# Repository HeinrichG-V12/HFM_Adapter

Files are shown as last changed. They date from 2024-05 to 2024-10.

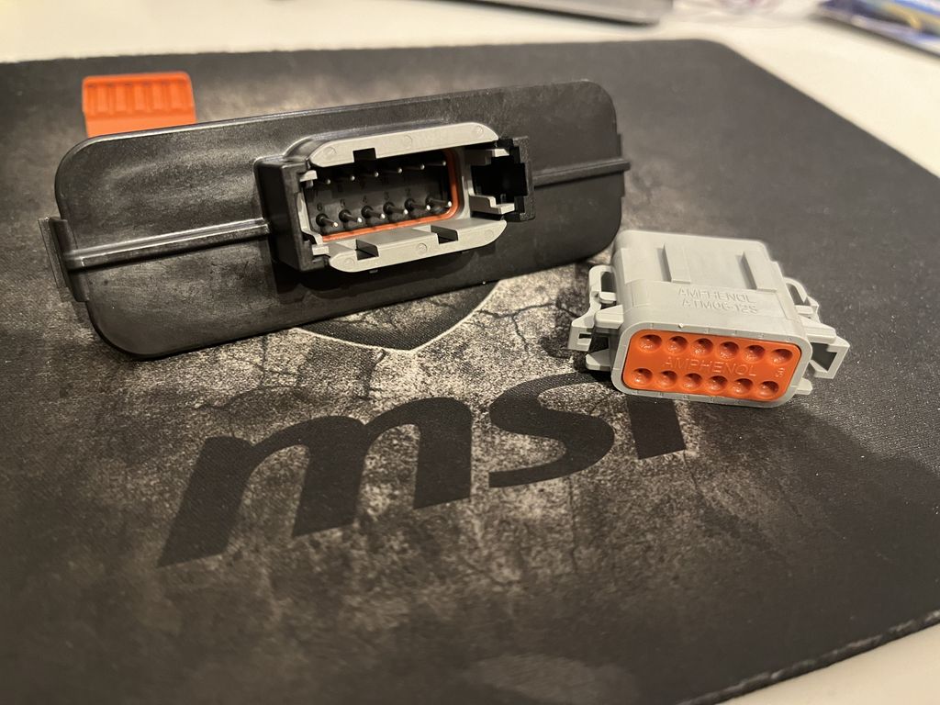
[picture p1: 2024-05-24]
hardware/Housing/003.jpg

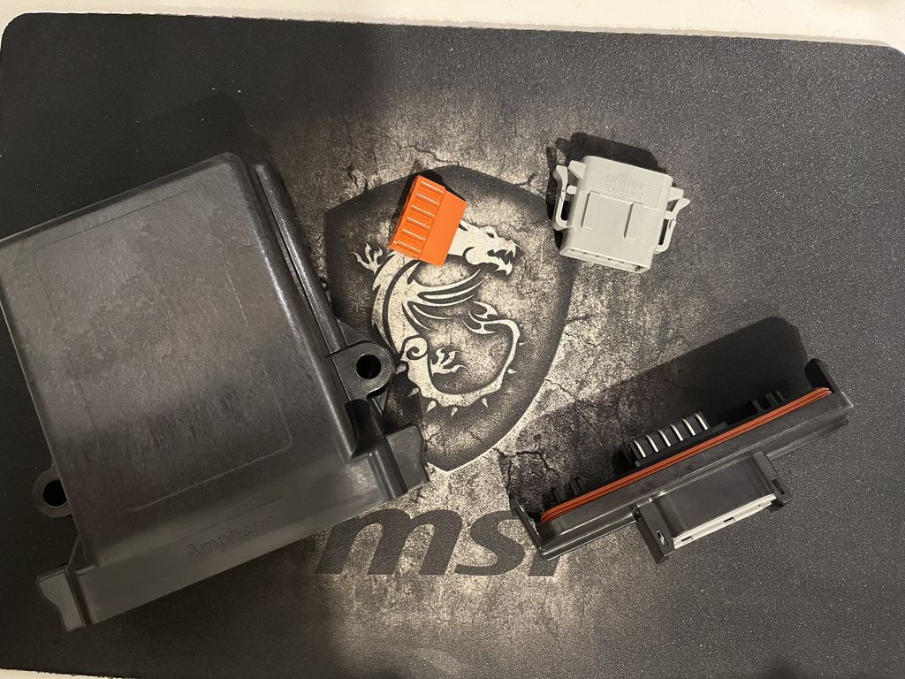
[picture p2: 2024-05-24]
hardware/Housing/001.jpg

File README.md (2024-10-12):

# HFM Adapter

## With this adapter it is possible to replace any HLM with any HFM

## Development status

- Hardware: Revision 1.0 done
  - [**Revision 1.0 is erroneous, swapped pins on TLE42764 and TLE4252D.**](./hardware/Rev1.0/README.md)
  - [Revision 1.1 done](./hardware/Rev1.1/README.md)
- Software: Version 1.0 done

### HFM Adapter based on

- STM32 G431KB Nucleo-32 Board
- ST M24M02 2MBit serial I²C EEPROM to store the tables and configuration
- TI REF02 +5.0v precision voltage reference, +-0.2%
- Infineon TLE4252D tracking regulator 250mA
- TI OPA2992 output operation amplifier

### Nucleo-32 modifications

A few changes need to be made to the Nucleo-32 board before it can be used:

- SB1 and SB12 removed (disconnect PA2 and PA3 from T_VCP_TX and T_VCP_RX of ST-Link)
- SB14 installed (connect PA3 to CN3 Pin 10)
- SB9 and SB10 installed (connect external 24MHz HSE CLK)

### Features

- Automotive grade components
- 4 layer PCB
- Configuration via TunerStudio

### Inputs

- two HFM buffered analog inputs (0v - 5v) with overvoltage protection 
- USB for configuration
- VBat input for voltage monitoring 

### Outputs

- two analog outputs
- two precision reference 5.0v outputs for HFM
- two Vbat outputs for HFM

### Housing

- Header: Amphenol ATM13-12PA
- Enclosure: Amphenol AIPXE-325X4

### Pin terminal for BMW M70 adapter

- pin terminal 1252 1718125
- connector boot 1252 1711262
- pins
  - 0.5 - 1.0mm² 6113 1376191
  - 1.0mm² - 2.5mm² 6113 1376193
  - 2.5mm² - 4.0mm² 6113 1376195

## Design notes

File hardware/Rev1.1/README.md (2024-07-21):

# HFM Adapter

## Revision 1.1

[Schematic](./hfm_adapter_nucleo-32.pdf)

Pinout

|Pin#|Wire size|Main color|Second color|Signal|
|----|---|---|---|---|
|1|0.5mm²|brown|-|signal ground|
|2|0.5mm²|brown|-|signal ground|
|3|0.5mm²|red|blue|VBat|
|4|0.5mm²|red|blue|VBat|
|5|0.5mm²|violett|black|5v reference voltage for HFM|
|6|0.5mm²|brown|-|signal ground|
|7|0.5mm²|red|blue|VBat|
|8|0.5mm²|violet|black|5v reference voltage for HFM|
|9|0.5mm²|violet|yellow|Channel 1 input from HFM|
|10|0.5mm²|orange|yellow|Channel 2 input from HFM|
|11|0.5mm²|violet|green|Channel 1 output to ECM|
|12|0.5mm²|orange|green|Channel 2 output to ECM|

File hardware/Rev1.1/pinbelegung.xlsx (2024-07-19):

Pin# | Querrschnitt | Hauptfarbe | Zusatzfarbe | Signal
1 | 0,5mm² | braun | - | Signalmasse
2 | 0,5mm² | braun | - | Signalmasse
3 | 0,5mm² | rot | blau | Ubat
4 | 0,5mm² | rot | blau | Ubat
5 | 0,5mm² | violett | schwarz | 5v Referenzspannung für HFM, falls notwendig
6 | 0,5mm² | braun | - | Signalmasse
7 | 0,5mm² | rot | blau | Ubat
8 | 0,5mm² | orange | schwarz | 5v Referenzspannung für HFM, falls notwendig
9 | 0,5mm² | violett | gelb | Kanal 1 Eingang vom HFM
10 | 0,5mm² | orange | gelb | Kanal 2 Eingang vom HFM
11 | 0,5mm² | violett | grün | Kanal 1 Ausgang zum Auto
12 | 0,5mm² | orange | grün | Kanal 2 Ausgang zum Auto

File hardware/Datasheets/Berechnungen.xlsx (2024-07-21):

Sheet: Tabelle1
Signature | 27
Version | 3
Versioninfo | 34
 | 64
hfmIn_voltage | 64 | 1
hfmIn_voltage | 65 | 2
hfmIn_voltage | 66 | 3
hfmIn_voltage | 67 | 4
hfmIn_voltage | 68 | 5
hfmIn_voltage | 69 | 6
hfmIn_voltage | 70 | 7
hfmIn_voltage | 71 | 8
hfmIn_voltage | 72 | 9
hfmIn_voltage | 73 | 10
hfmIn_voltage | 74 | 11
hfmIn_voltage | 75 | 12
hfmIn_voltage | 76 | 13
hfmIn_voltage | 77 | 14
hfmIn_voltage | 78 | 15
hfmIn_voltage | 79 | 16
hfmIn_voltage | 80 | 17
hfmIn_voltage | 81 | 18
hfmIn_voltage | 82 | 19
hfmIn_voltage | 83 | 20
hfmIN_airmass | 84 | 1
hfmIN_airmass | 85 | 2
hfmIN_airmass | 86 | 3
hfmIN_airmass | 87 | 4
hfmIN_airmass | 88 | 5
hfmIN_airmass | 89 | 6
hfmIN_airmass | 90 | 7
hfmIN_airmass | 91 | 8
hfmIN_airmass | 92 | 9
hfmIN_airmass | 93 | 10
hfmIN_airmass | 94 | 11
hfmIN_airmass | 95 | 12
hfmIN_airmass | 96 | 13
hfmIN_airmass | 97 | 14
hfmIN_airmass | 98 | 15
hfmIN_airmass | 99 | 16
hfmIN_airmass | 100 | 17
hfmIN_airmass | 101 | 18
hfmIN_airmass | 102 | 19
hfmIN_airmass | 103 | 20
hfmOUT_voltage | 104 | 1
hfmOUT_voltage | 105 | 2
hfmOUT_voltage | 106 | 3
hfmOUT_voltage | 107 | 4
hfmOUT_voltage | 108 | 5
hfmOUT_voltage | 109 | 6
hfmOUT_voltage | 110 | 7
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

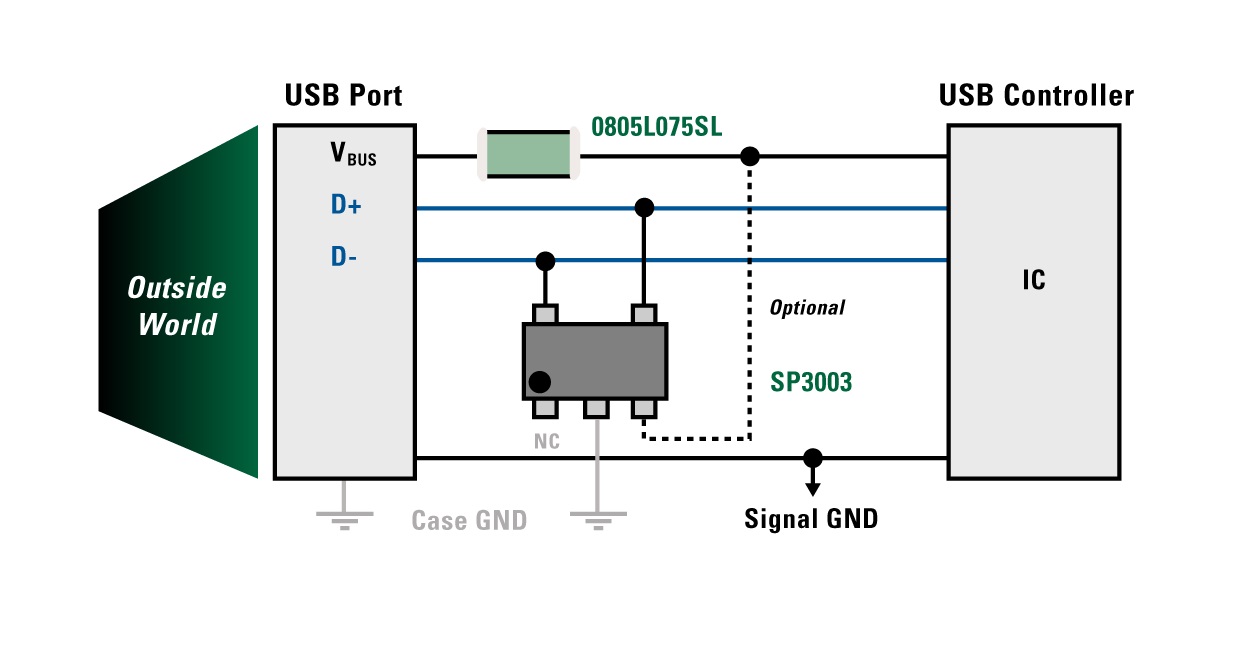
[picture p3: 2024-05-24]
hardware/Datasheets/02apr14protectfig3.jpg

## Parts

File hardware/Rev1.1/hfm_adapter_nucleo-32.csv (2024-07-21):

Qty | Value | Device | Package | Parts | Description | ARROW_PART_NUMBER | ARROW_PRICE-STOCK | DESCRIPTION | HEIGHT | MANUFACTURER_NAME | MANUFACTURER_PART_NUMBER | MF | MOUSER_PART_NUMBER | MOUSER_PRICE-STOCK | MPN | OC_FARNELL | OC_NEWARK | RS_PART_NUMBER | RS_PRICE-STOCK | SPICEPREFIX
10 | 100nF | C-EUC0805 | C0805 | C2, C4, C5, C8, C9, C10, C13, C14, C15, C17 | CAPACITOR, European symbol |  |  |  |  |  |  |  |  |  |  |  |  |  |  | C
1 | 100nF | C-EUC1206 | C1206 | C6 | CAPACITOR, European symbol |  |  |  |  |  |  |  |  |  |  |  |  |  |  | C
8 | 10k 0.5% | R-EU_R0805 | R0805 | R4, R6, R8, R11, R12, R14, R15, R16 | RESISTOR, European symbol |  |  |  |  |  |  |  |  |  |  |  |  |  |  | R
1 | 10µF 50v | CPOL-EUD | PANASONIC_D | C12 | POLARIZED CAPACITOR, European symbol |  |  |  |  |  |  |  |  |  |  |  |  |  |  | C
3 | 1uF | C-EUC0805 | C0805 | C1, C11, C16 | CAPACITOR, European symbol |  |  |  |  |  |  |  |  |  |  |  |  |  |  | C
1 | 22µF | CPOL-EUC | PANASONIC_C | C7 | POLARIZED CAPACITOR, European symbol |  |  |  |  |  |  |  |  |  |  |  |  |  |  | C
1 | 30k 0.5% | R-EU_R0805 | R0805 | R9 | RESISTOR, European symbol |  |  |  |  |  |  |  |  |  |  |  |  |  |  | R
2 | 470k | R-EU_R0805 | R0805 | R18, R19 | RESISTOR, European symbol |  |  |  |  |  |  |  |  |  |  |  |  |  |  | R
2 | 4k7 | R-EU_R0805 | R0805 | R1, R2 | RESISTOR, European symbol |  |  |  |  |  |  |  |  |  |  |  |  |  |  | R
4 | 5k6 0.5% | R-EU_R0805 | R0805 | R3, R5, R7, R10 | RESISTOR, European symbol |  |  |  |  |  |  |  |  |  |  |  |  |  |  | R
1 | 82k 0.5% | R-EU_R0805 | R0805 | R13 | RESISTOR, European symbol |  |  |  |  |  |  |  |  |  |  |  |  |  |  | R
1 | ADR01_02_03 | ADR01_02_03 | SOIC8 | IC9
1 | ATM13-12PX | ATM13-12PX | ATM13-12PX | HOUSING
1 | B5819W | SHOTTKYSOD-123 | SOD-123 | D4
1 | BAT54S | BAT54S | SOT23 | D1 | Schottky barrier (double) diodesPlanar Schottky barrier diodes encapsulated in a SOT23
1 | IP4234CZ6,115 | IP4234CZ6,115 | SOT95P275X110-6N | IC3 | ESD Suppressors / TVS Diodes ESD PRTCT/HI SPD INF ZEN LOW VLTG CLMP | IP4234CZ6,115 | null?region=nac | ESD Suppressors / TVS Diodes ESD PRTCT/HI SPD INF ZEN LOW VLTG CLMP | 1.1mm | Nexperia | IP4234CZ6,115 |  | 771-IP4234CZ6 | https://www.mouser.co.uk/ProductDetail/Nexperia/IP4234CZ6115?qs=iS%252BvaFGfLooAQ%252BprbRTkIg%3D%3D
1 | KUSBVX-BS1N | KUSBVX-BS1N | KUSBVX-BS1N | X2 | USB B-type Receptacle Vertical, 4 Position, Through Hole
1 | LPS25HBTR | LPS25HBTR | LPS25HBTR | IC4 | Board Mount Pressure Sensor 26kPa to 126kPa Absolute 10-Pin HLGA T/R | LPS25HBTR | https://www.arrow.com/en/products/lps25hbtr/stmicroelectronics | Board Mount Pressure Sensor 26kPa to 126kPa Absolute 10-Pin HLGA T/R | 0.8mm | STMicroelectronics | LPS25HBTR |  | 511-LPS25HBTR | https://www.mouser.co.uk/ProductDetail/STMicroelectronics/LPS25HBTR?qs=GDOUxV2YAh9IvjPyBKWGzQ%3D%3D
1 | M24M02 | EEPROM_I2CSO8 | SO8 | IC2 | I²C EEPROM IC, i.e. FT24C256A
1 | NUCLEO-G431KB | NUCLEO-G431KB | DIPS1524W66P254L5029H1500Q30N | IC1 | STM32 Nucleo-32 development board | NUCLEO-F303K8 | https://www.arrow.com/en/products/nucleo-f303k8/stmicroelectronics | STM32 Nucleo-32 development board | 15mm | STMicroelectronics | NUCLEO-F303K8 |  |  |  |  |  |  | 9092862 | http://uk.rs-online.com/web/p/products/9092862
1 | OPA2172D | OPA2172D | SO08 | IC11 | Operational Amplifier |  |  |  |  |  |  | TEXAS INSTRUMENTS |  |  | OPA2234U | 1212441 | 96K4523
1 | OPA2992D | OPA2172D | SO08 | IC10 | Operational Amplifier |  |  |  |  |  |  | TEXAS INSTRUMENTS |  |  | OPA2234U | 1212441 | 96K4523
1 | S1J | SHOTTKYSMA | DO214AC | D5
1 | SMBJ36CA | TVS_BIA | DO214AA | D2
1 | SRV05-4MR6T1GTSSOP6 | SRV05-4MR6T1GTSSOP6 | TSSOP6 | IC6 |  | SRV05-4MR6T1G | https://www.arrow.com/en/products/srv05-4mr6t1g/on-semiconductor?region=nac | ON SEMICONDUCTOR - SRV05-4MR6T1G - ESD Protection Device, 17.5 V, TSOP, 6 Pins, 300 W | 1.1mm | onsemi | SRV05-4MR6T1G |  | 863-SRV05-4MR6T1G | https://www.mouser.co.uk/ProductDetail/onsemi/SRV05-4MR6T1G?qs=unWjWFgkqcg61n2fM3DdZg%3D%3D
1 | TLE4252D | TLE4252D | TO-252-5-INF | IC7 | Infineon Tracking regualtor
1 | TLE42764DV | TLE42764DV | TO-252-5-INF | IC8

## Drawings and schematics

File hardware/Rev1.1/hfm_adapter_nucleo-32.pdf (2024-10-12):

A

A

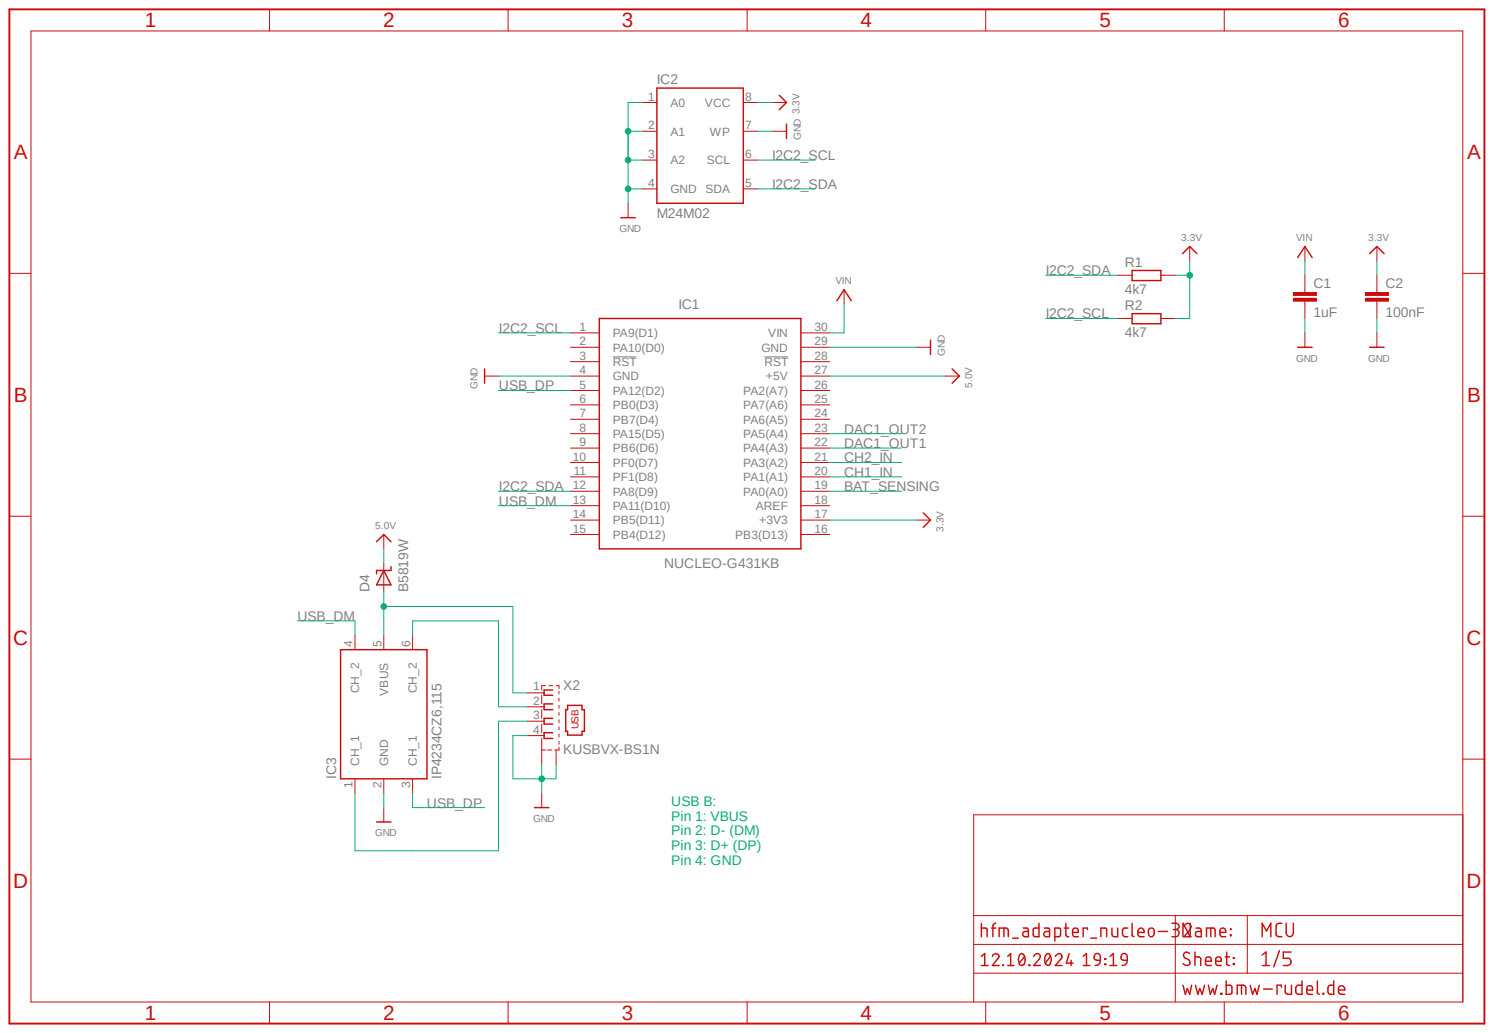
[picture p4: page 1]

A

A

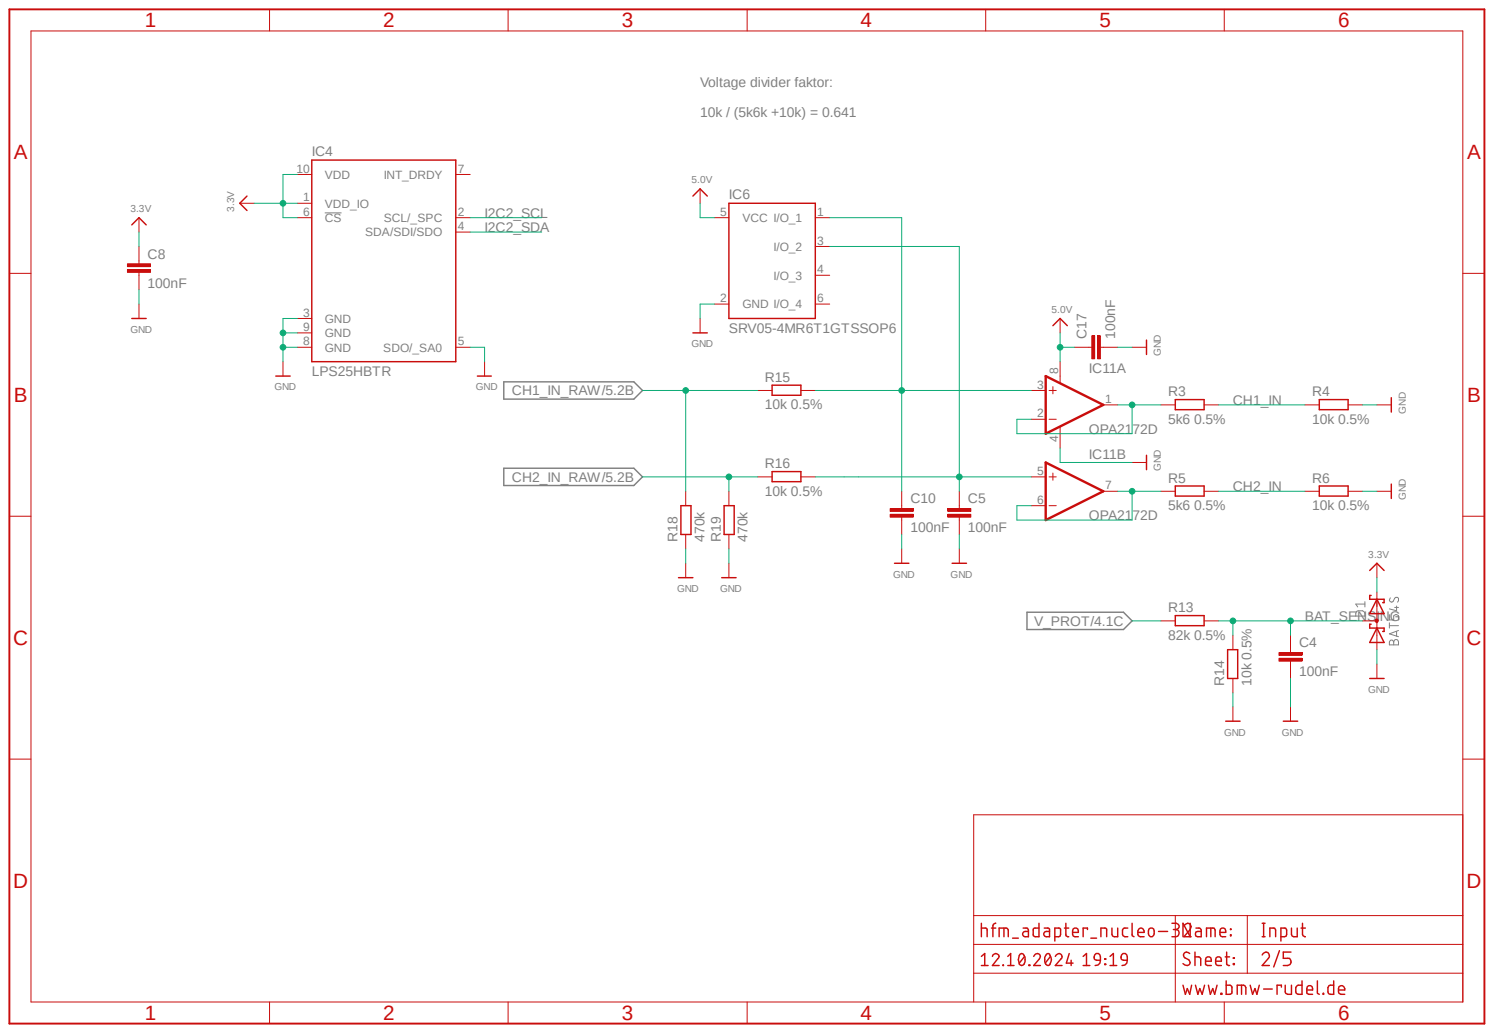
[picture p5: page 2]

A

A

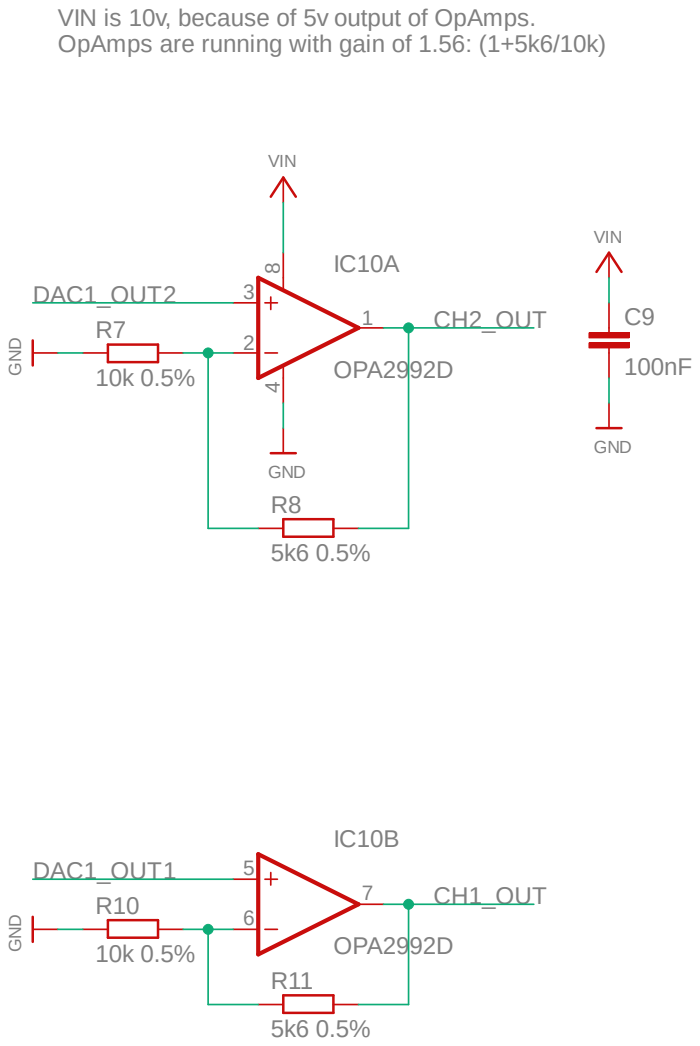
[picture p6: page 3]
GND; GNDGND GND100nF; VIN; OPA2992D; CH2_OUT; CH1_OUT; DAC1_OUT1; DAC1_OUT2

VIN is 10v, because of 5v output of OpAmps.
OpAmps are running with gain of 1.56: (1+5k6/10k)

A

A

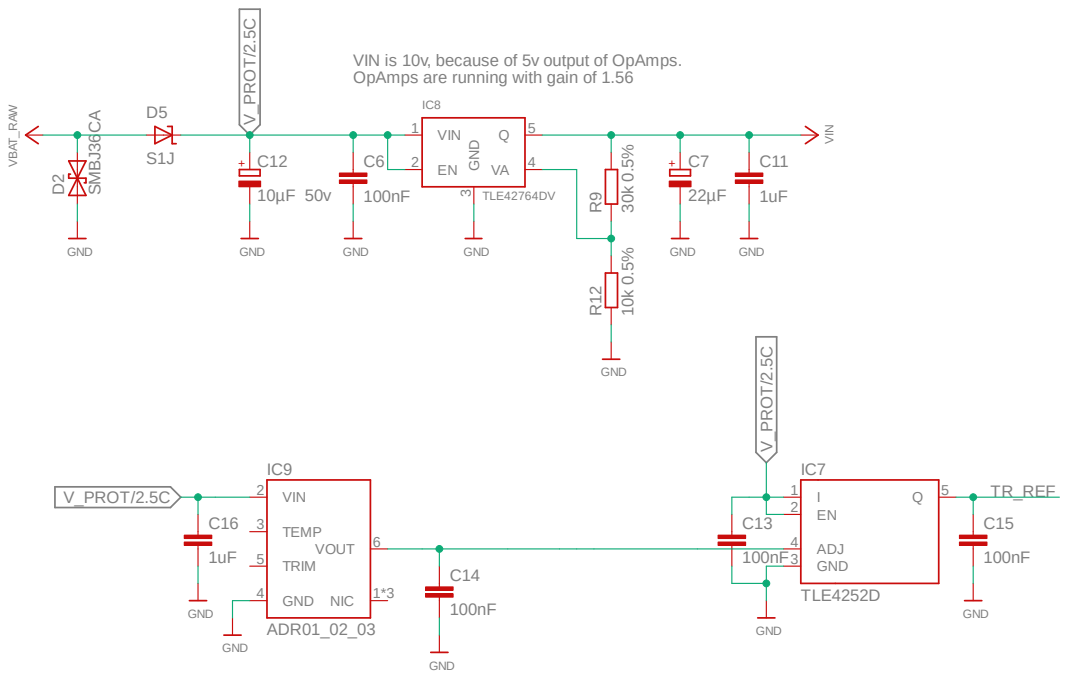
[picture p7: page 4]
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

A

A

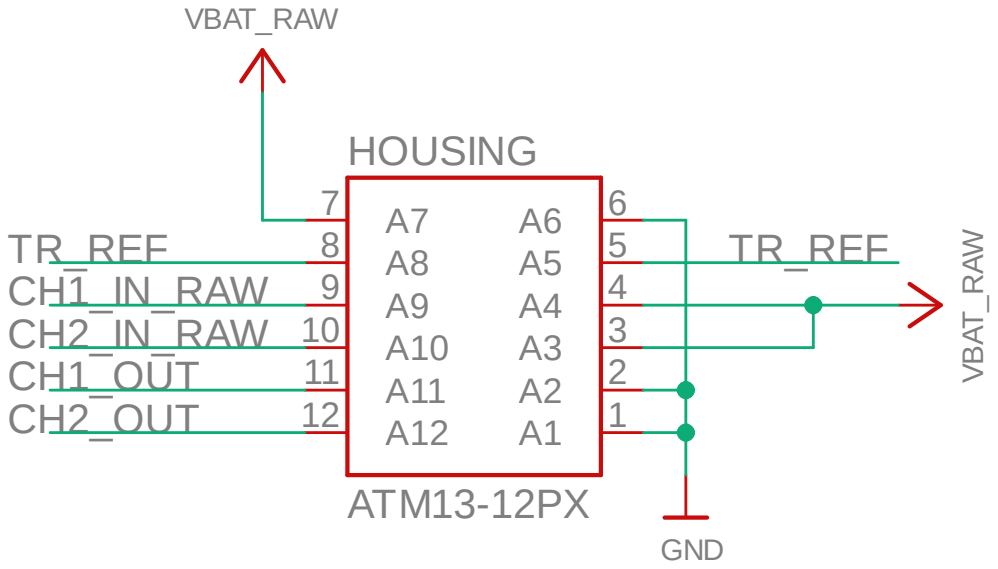
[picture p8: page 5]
ATM13-12PX; GND; VBAT_RAW; VBAT_RAWA6 6 A5 5 A4 4 A3 3 A2 2; HOUSING; CH1_IN_RAW CH2_IN_RAW; TR_REFTR_REF; CH1_OUT CH2_OUT

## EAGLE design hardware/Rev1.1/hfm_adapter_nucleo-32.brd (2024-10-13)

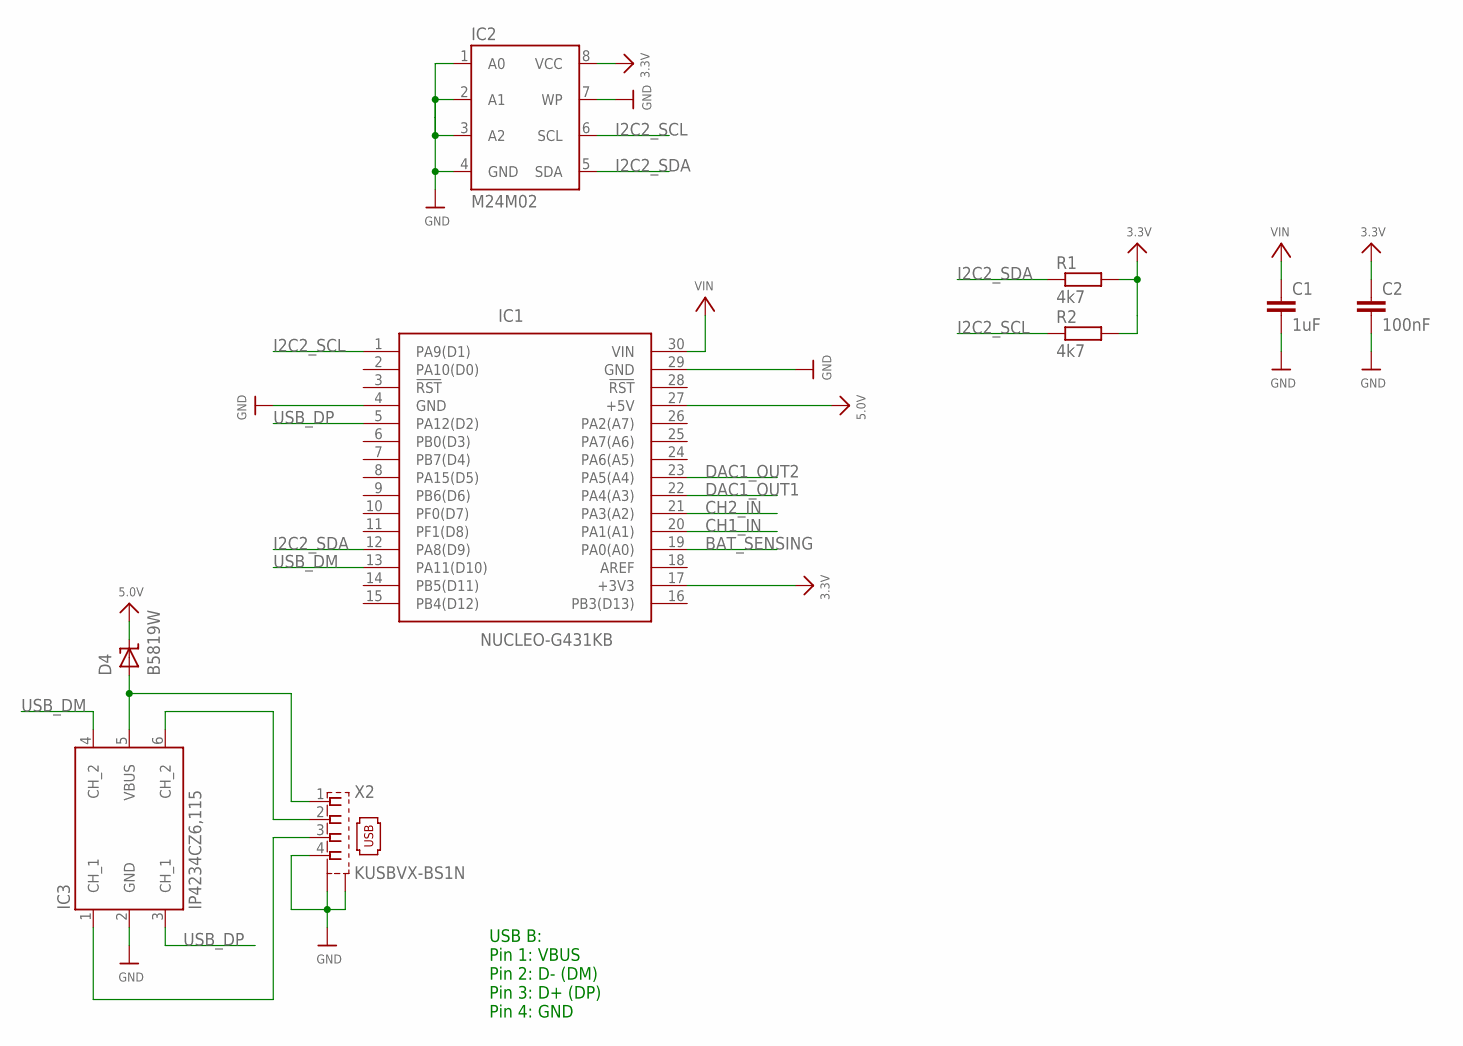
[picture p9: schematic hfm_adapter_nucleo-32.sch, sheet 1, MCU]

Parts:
C1: 1uF; C0805
C2: 100nF; C0805
D4: B5819W; SOD-123
IC1: NUCLEO-G431KB; DIPS1524W66P254L5029H1500Q30N
IC2: M24M02; SO8
IC3: IP4234CZ6,115; SOT95P275X110-6N
R1, R2: 4k7; R0805
X2: KUSBVX-BS1N

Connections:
3.3V: C2.1, IC1.17 (+3V3), IC2.8 (VCC), R1.2, R2.2; also elsewhere on the board
5.0V: D4.C, IC1.27 (+5V); also elsewhere on the board
BAT_SENSING: IC1.19 (PA0(A0)); also elsewhere on the board
CH1_IN: IC1.20 (PA1(A1)); also elsewhere on the board
CH2_IN: IC1.21 (PA3(A2)); also elsewhere on the board
DAC1_OUT1: IC1.22 (PA4(A3)); also elsewhere on the board
DAC1_OUT2: IC1.23 (PA5(A4)); also elsewhere on the board
GND: C1.2, C2.2, IC1.4 (GND), IC1.29 (GND), IC2.1 (A0), IC2.2 (A1), IC2.3 (A2), IC2.4 (GND), IC2.7 (WP), IC3.2 (GND), X2.4, X2.M1 (S1), X2.M2 (S2); also elsewhere on the board
I2C2_SCL: IC1.1 (PA9(D1)), IC2.6 (SCL), R2.1; also elsewhere on the board
I2C2_SDA: IC1.12 (PA8(D9)), IC2.5 (SDA), R1.1; also elsewhere on the board
unnamed: IC3.1 (CH_1), X2.3
unnamed: IC3.6 (CH_2), X2.2
unnamed: D4.A, IC3.5 (VBUS), X2.1
USB_DM: IC1.13 (PA11(D10)), IC3.4 (CH_2)
USB_DP: IC1.5 (PA12(D2)), IC3.3 (CH_1)
VIN: C1.1, IC1.30 (VIN); also elsewhere on the board

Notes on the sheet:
USB B: Pin 1: VBUS Pin 2: D- (DM) Pin 3: D+ (DP) Pin 4: GND

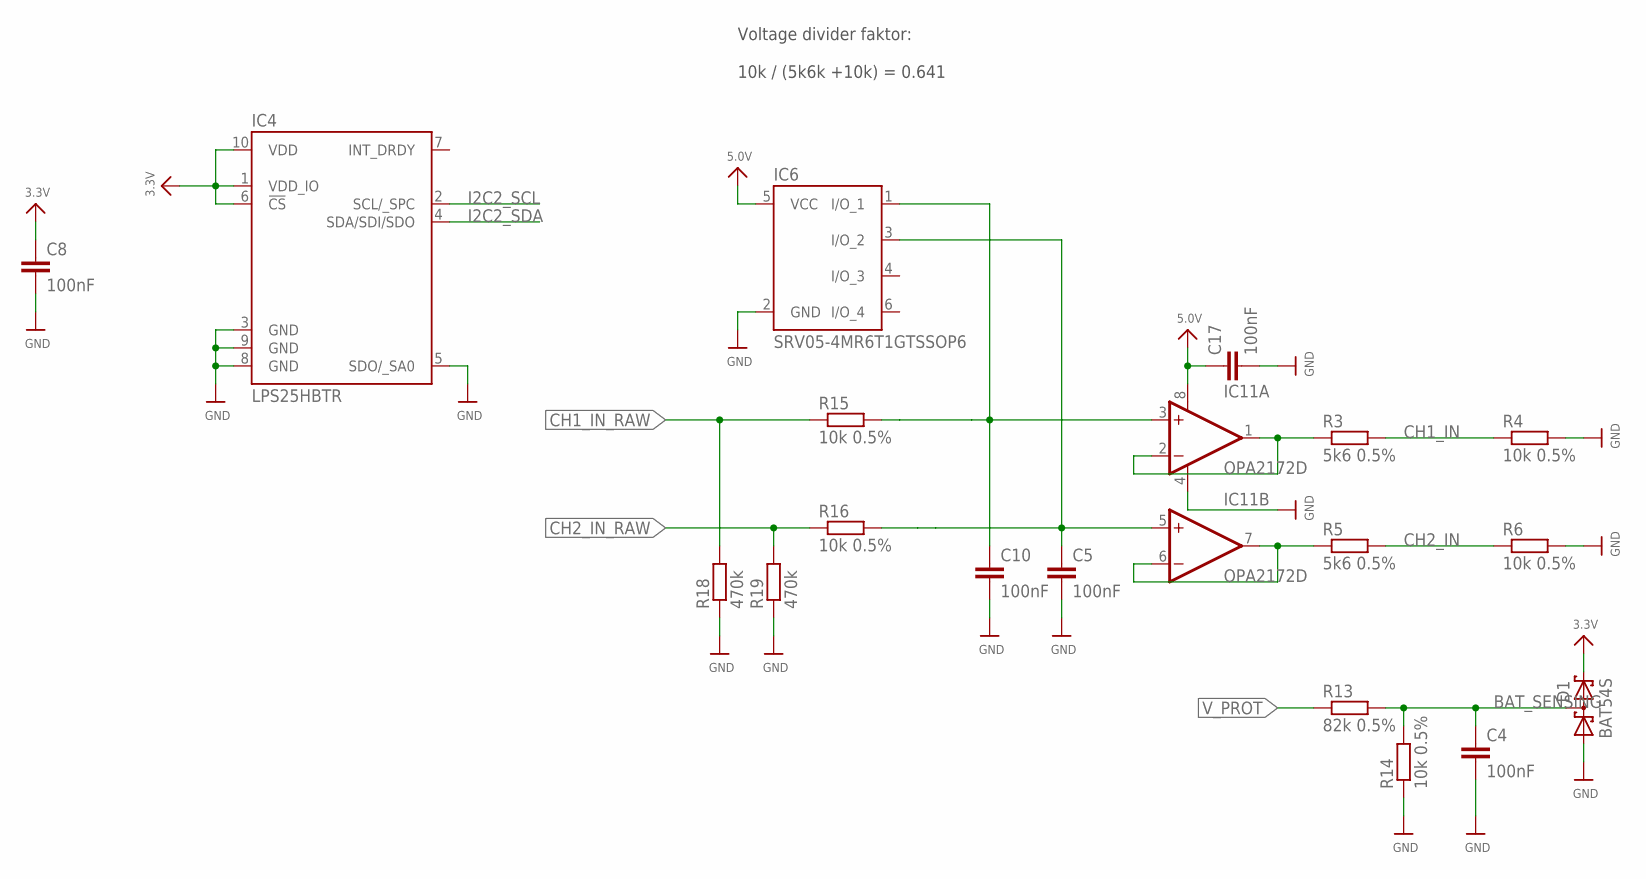
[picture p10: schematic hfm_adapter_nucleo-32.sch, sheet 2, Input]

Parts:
C4, C5, C8, C10, C17: 100nF; C0805
D1: BAT54S; SOT23
IC4: LPS25HBTR
IC6: SRV05-4MR6T1GTSSOP6; TSSOP6
IC11: OPA2172D; SO08
R3, R5: 5k6 0.5%; R0805
R4, R6, R14, R15, R16: 10k 0.5%; R0805
R13: 82k 0.5%; R0805
R18, R19: 470k; R0805

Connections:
3.3V: C8.1, D1.2 (K2), IC4.1 (VDD_IO), IC4.6 (!CS), IC4.10 (VDD); also elsewhere on the board
5.0V: C17.1, IC6.5 (VCC), IC11.8 (V+); also elsewhere on the board
BAT_SENSING: C4.1, D1.3 (K1A2), R13.2, R14.2; also elsewhere on the board
CH1_IN: R3.2, R4.1; also elsewhere on the board
CH1_IN_RAW: R15.1, R18.2; also elsewhere on the board
CH2_IN: R5.2, R6.1; also elsewhere on the board
CH2_IN_RAW: R16.1, R19.2; also elsewhere on the board
GND: C4.2, C5.2, C8.2, C10.2, C17.2, D1.1 (A1), IC4.3 (GND), IC4.5 (SDO/_SA0), IC4.8 (GND), IC4.9 (GND), IC6.2 (GND), IC11.4 (V-), R4.2, R6.2, R14.1, R18.1, R19.1; also elsewhere on the board
I2C2_SCL: IC4.2 (SCL/_SPC); also elsewhere on the board
I2C2_SDA: IC4.4 (SDA/SDI/SDO); also elsewhere on the board
unnamed: IC11.1 (OUT), IC11.2 (-IN), R3.1
unnamed: C10.1, IC6.1 (I/O_1), IC11.3 (+IN), R15.2
unnamed: IC11.6 (-IN), IC11.7 (OUT), R5.1
unnamed: C5.1, IC6.3 (I/O_2), IC11.5 (+IN), R16.2
V_PROT: R13.1; also elsewhere on the board

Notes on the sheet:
Voltage divider faktor: 10k / (5k6k +10k) = 0.641

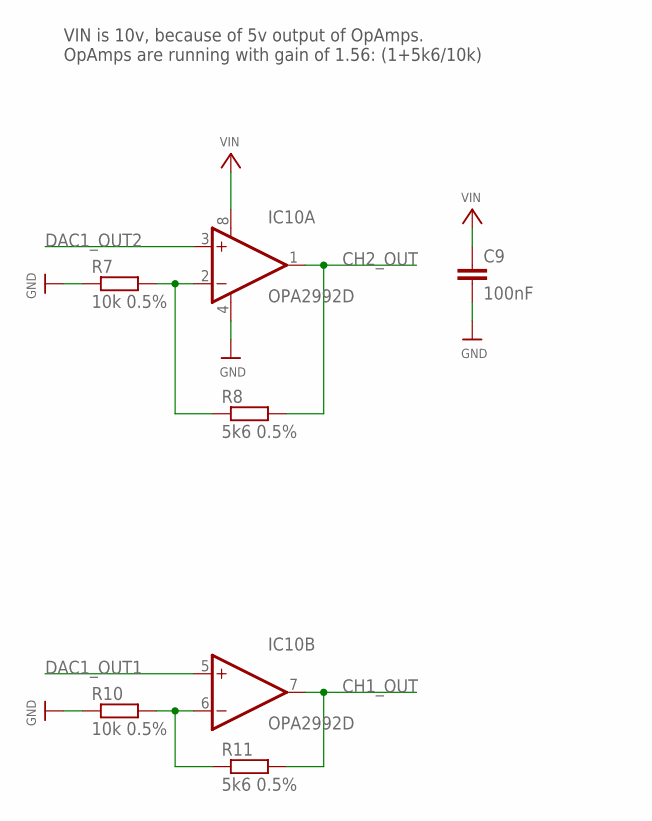
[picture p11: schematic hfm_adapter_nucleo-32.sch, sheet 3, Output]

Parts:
C9: 100nF; C0805
IC10: OPA2992D; SO08
R7, R10: 10k 0.5%; R0805
R8, R11: 5k6 0.5%; R0805

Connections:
CH1_OUT: IC10.7 (OUT), R11.2; also elsewhere on the board
CH2_OUT: IC10.1 (OUT), R8.2; also elsewhere on the board
DAC1_OUT1: IC10.5 (+IN); also elsewhere on the board
DAC1_OUT2: IC10.3 (+IN); also elsewhere on the board
GND: C9.2, IC10.4 (V-), R7.1, R10.1; also elsewhere on the board
unnamed: IC10.6 (-IN), R10.2, R11.1
unnamed: IC10.2 (-IN), R7.2, R8.1
VIN: C9.1, IC10.8 (V+); also elsewhere on the board

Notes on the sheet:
VIN is 10v, because of 5v output of OpAmps. OpAmps are running with gain of 1.56: (1+5k6/10k)

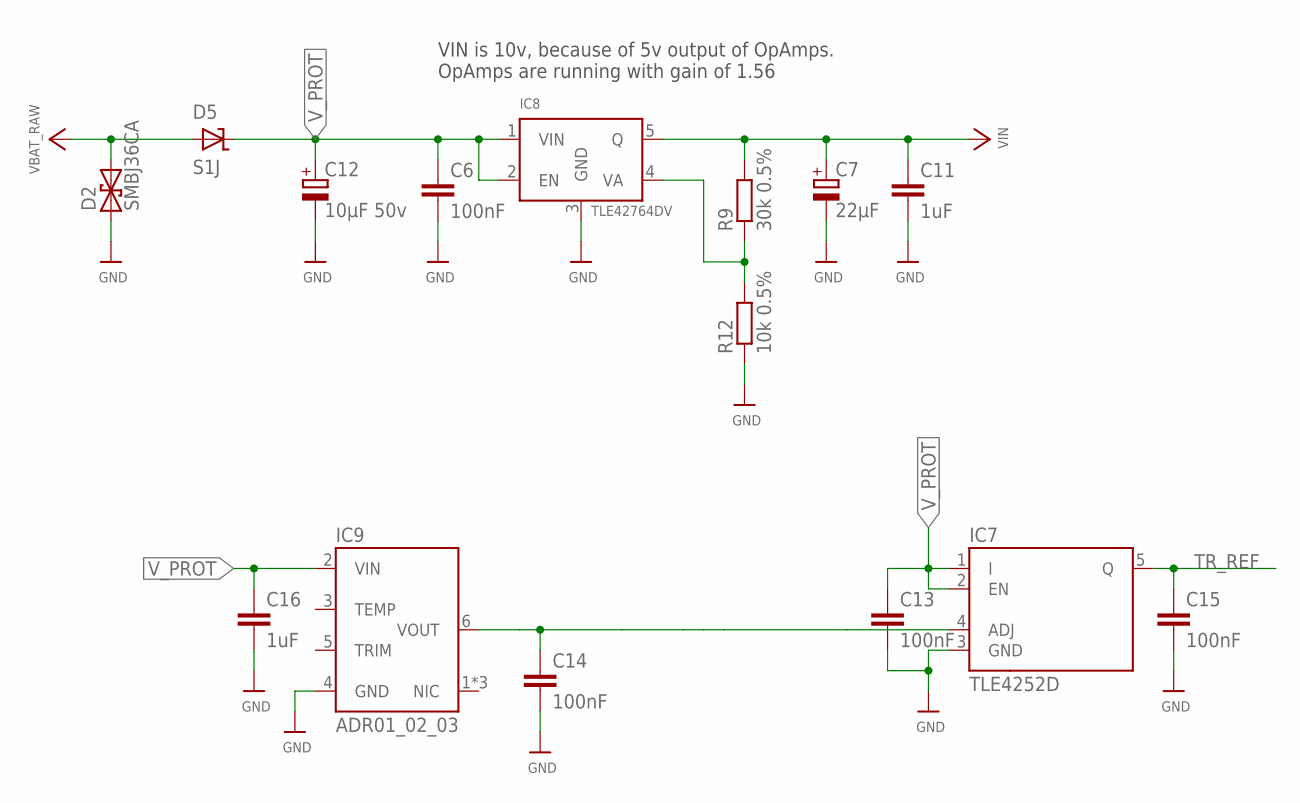
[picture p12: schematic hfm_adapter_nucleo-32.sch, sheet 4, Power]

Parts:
C6: 100nF; C1206
C7: 22µF; PANASONIC_C
C11, C16: 1uF; C0805
C12: 10µF 50v; PANASONIC_D
C13, C14, C15: 100nF; C0805
D2: SMBJ36CA; DO214AA
D5: S1J; DO214AC
IC7: TLE4252D; TO-252-5-INF
IC8: TLE42764DV; TO-252-5-INF
IC9: ADR01_02_03; SOIC8
R9: 30k 0.5%; R0805
R12: 10k 0.5%; R0805

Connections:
GND: C6.2, C7.-, C11.2, C12.-, C13.2, C14.2, C15.2, C16.2, D2.A (1), IC7.3 (GND), IC8.3 (GND), IC9.4 (GND), R12.1; also elsewhere on the board
unnamed: IC8.4 (VA), R9.1, R12.2
TR_REF: C15.1, IC7.5 (Q); also elsewhere on the board
VBAT_RAW: D2.C (2), D5.A; also elsewhere on the board
VIN: C7.+, C11.1, IC8.5 (Q), R9.2; also elsewhere on the board
VREF: C14.1, IC7.4 (ADJ), IC9.6 (VOUT)
V_PROT: C6.1, C12.+, C13.1, C16.1, D5.C, IC7.1 (I), IC7.2 (EN), IC8.1 (VIN), IC8.2 (EN), IC9.2 (VIN); also elsewhere on the board

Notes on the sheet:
VIN is 10v, because of 5v output of OpAmps. OpAmps are running with gain of 1.56

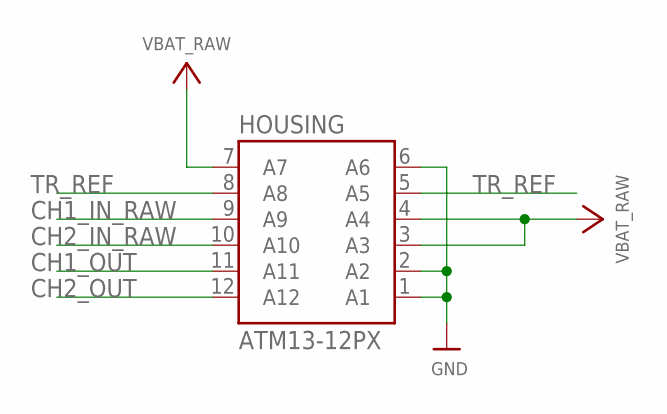
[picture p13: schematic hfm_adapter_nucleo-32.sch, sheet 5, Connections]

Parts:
HOUSING: ATM13-12PX

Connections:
CH1_IN_RAW: HOUSING.9 (A9); also elsewhere on the board
CH1_OUT: HOUSING.11 (A11); also elsewhere on the board
CH2_IN_RAW: HOUSING.10 (A10); also elsewhere on the board
CH2_OUT: HOUSING.12 (A12); also elsewhere on the board
GND: HOUSING.1 (A1), HOUSING.2 (A2), HOUSING.6 (A6); also elsewhere on the board
TR_REF: HOUSING.5 (A5), HOUSING.8 (A8); also elsewhere on the board
VBAT_RAW: HOUSING.3 (A3), HOUSING.4 (A4), HOUSING.7 (A7); also elsewhere on the board

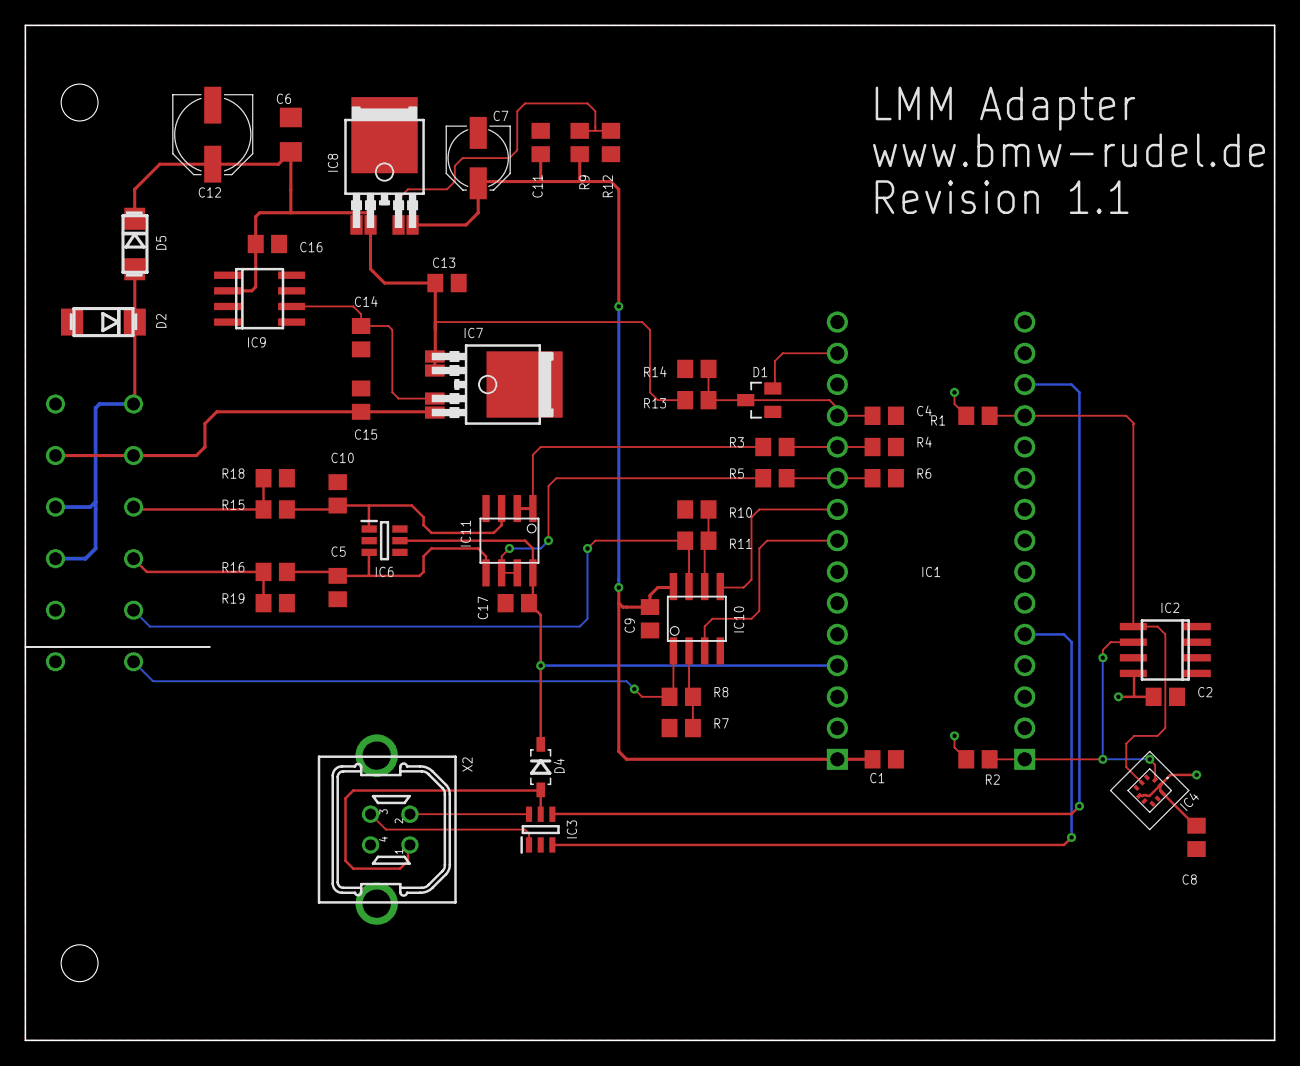
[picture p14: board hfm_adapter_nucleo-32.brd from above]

Board: 4 copper layers, 101.6 x 82.5 mm, 50 parts (0 on the bottom side), 31 nets.

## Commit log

2024-05-24 Revision 1 done
    [Berechnungen.xlsx, hfm_adapter_nucleo-32.brd, hfm_adapter_nucleo-32.sch]
2024-06-03 some values changed, BOM added
    [Berechnungen.xlsx, hfm_adapter_nucleo-32.brd, hfm_adapter_nucleo-32.sch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]
2024-07-19 some changed rev 1.0
    [Berechnungen.xlsx, hfm_adapter_nucleo-32_bom.xlsx, pinbelegung.xlsx]
2024-07-21 some changeds
    [Berechnungen.xlsx]
2024-07-21 Revision 1.1
    [Berechnungen.xlsx, hfm_adapter_nucleo-32.brd, hfm_adapter_nucleo-32.csv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]
2024-07-25 some small changes
    [hfm_adapter_nucleo-32.brd, hfm_adapter_nucleo-32.sch]
2024-07-25 wire stubs removed
    [hfm_adapter_nucleo-32.brd]
2024-07-25 some minimal changes
    [hfm_adapter_nucleo-32.brd, hfm_adapter_nucleo-32.sch]
2024-10-12 nucleo-32 modifications and correct schematic
2024-10-13 amplification factor corrected
    [hfm_adapter_nucleo-32.brd, hfm_adapter_nucleo-32.sch]

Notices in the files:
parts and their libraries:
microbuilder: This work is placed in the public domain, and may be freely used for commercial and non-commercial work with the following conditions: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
